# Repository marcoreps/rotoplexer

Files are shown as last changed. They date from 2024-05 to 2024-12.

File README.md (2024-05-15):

# rotoplexer
 Nanovolt scanner with rotary switches, first draft for experimentation only

Inspired by
https://dataproof.com/Publications/NBS430.PDF
https://iopscience.iop.org/article/10.1088/0957-0233/24/2/025008

Python software example
https://github.com/marcoreps/multiinstrumentalist/blob/11b641b6d90bda38c73909955b253200de4179e4/main.py#L624

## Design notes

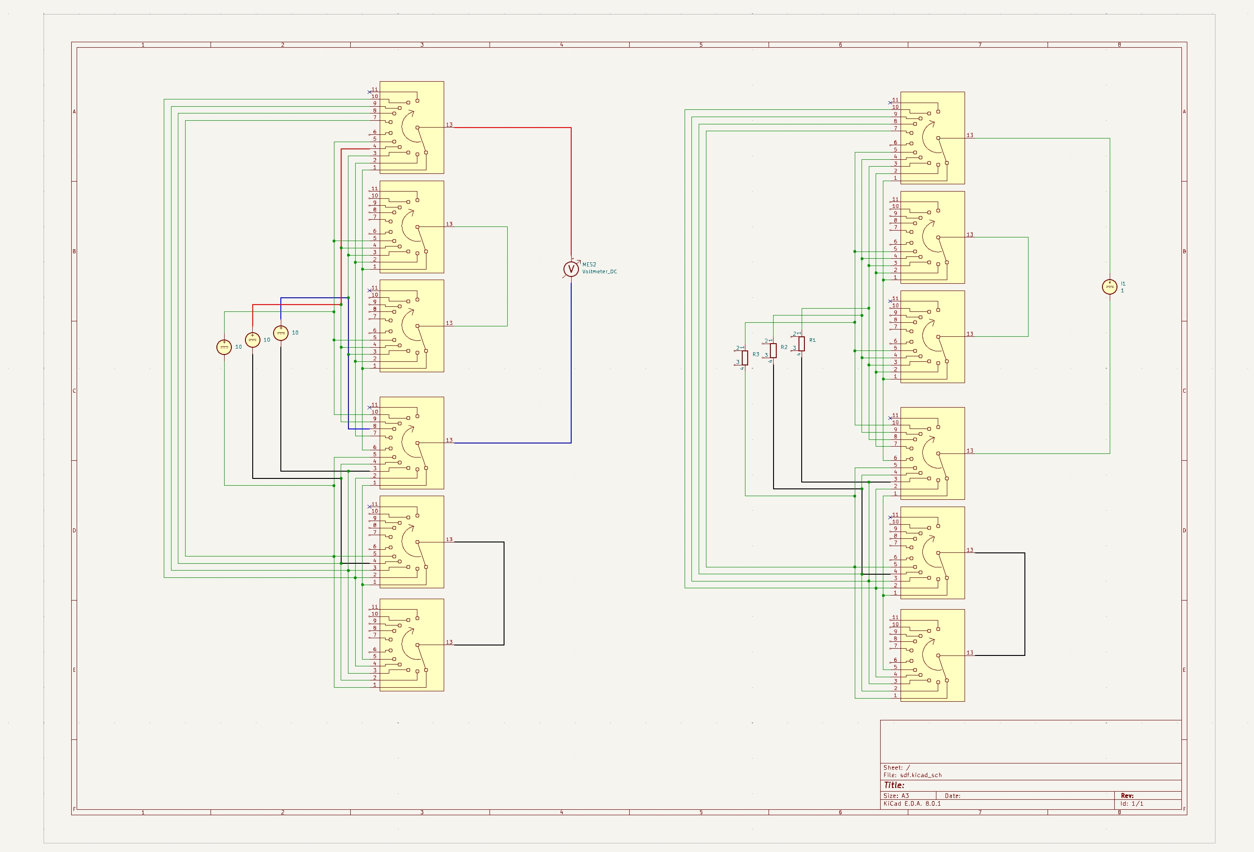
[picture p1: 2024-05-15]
electronics/nbs430 switch example.jpg

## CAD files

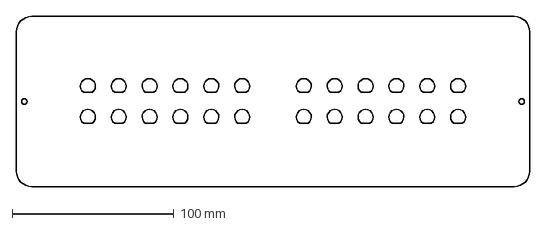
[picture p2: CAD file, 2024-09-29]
3d models/frontpanel.dxf
317.0 x 105.0 mm

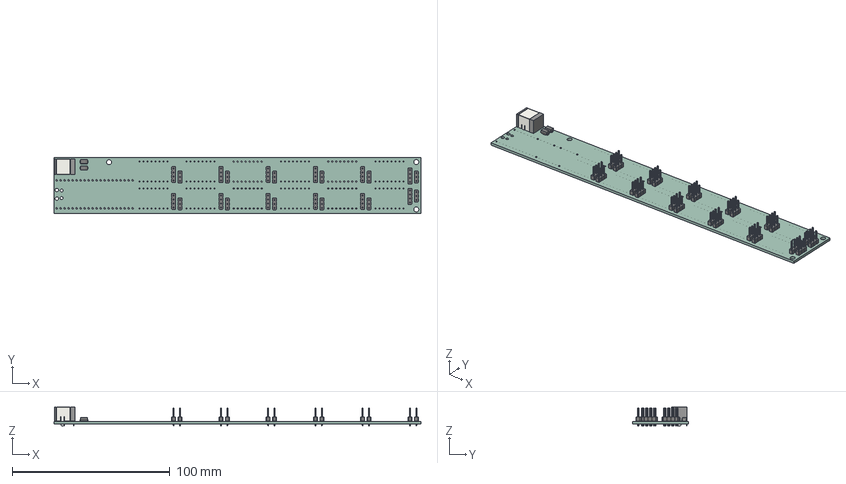
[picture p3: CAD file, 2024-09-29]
electronics/controller board/controller board.step
233.0 x 35.6 x 12.0 mm
PinHeader_1x04_P254mm_Vertical x 12
PinHeader_1x03_P254mm_Vertical x 12
D_SMA x 2
BarrelJack_CUI_PJ-063AH_Horizontal
controller board_PCB

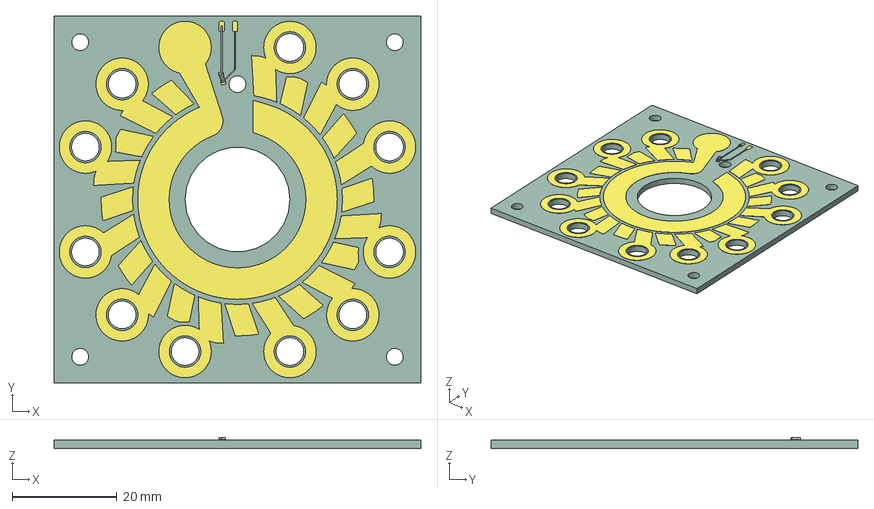
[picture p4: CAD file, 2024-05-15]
electronics/switch wafer pcb/rotary_switch_nv_scanner.step
70.0 x 70.0 x 2.10 mm
R_0603_1608Metric
rotary_switch_nv_scanner_track_1
rotary_switch_nv_scanner_track_2
rotary_switch_nv_scanner_track_3
rotary_switch_nv_scanner_track_4
rotary_switch_nv_scanner_track_5
rotary_switch_nv_scanner_track_6
rotary_switch_nv_scanner_track_7
rotary_switch_nv_scanner_track_8
rotary_switch_nv_scanner_track_9
rotary_switch_nv_scanner_track_10
rotary_switch_nv_scanner_track_11
rotary_switch_nv_scanner_track_12
rotary_switch_nv_scanner_track_13
rotary_switch_nv_scanner_track_14
rotary_switch_nv_scanner_track_15
rotary_switch_nv_scanner_track_16
rotary_switch_nv_scanner_track_17
rotary_switch_nv_scanner_track_18
rotary_switch_nv_scanner_track_19
rotary_switch_nv_scanner_track_20
rotary_switch_nv_scanner_track_21
rotary_switch_nv_scanner_track_22
rotary_switch_nv_scanner_track_23
rotary_switch_nv_scanner_track_24
rotary_switch_nv_scanner_track_25
rotary_switch_nv_scanner_track_26
rotary_switch_nv_scanner_track_27
rotary_switch_nv_scanner_pad_1
rotary_switch_nv_scanner_pad_2
rotary_switch_nv_scanner_pad_3
rotary_switch_nv_scanner_pad_4
rotary_switch_nv_scanner_pad_5
rotary_switch_nv_scanner_pad_6
rotary_switch_nv_scanner_pad_7
rotary_switch_nv_scanner_pad_8
rotary_switch_nv_scanner_pad_9
rotary_switch_nv_scanner_pad_10
rotary_switch_nv_scanner_pad_11
rotary_switch_nv_scanner_pad_12
rotary_switch_nv_scanner_pad_13
rotary_switch_nv_scanner_pad_14
rotary_switch_nv_scanner_PCB

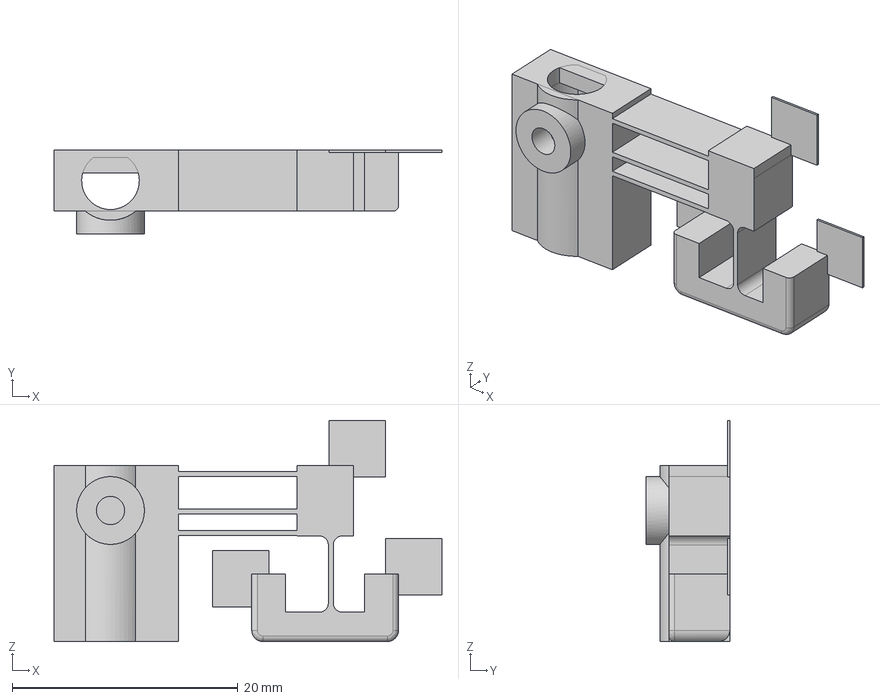
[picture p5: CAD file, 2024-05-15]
3d models/fdm wiper.step
34.3 x 7.40 x 19.6 mm

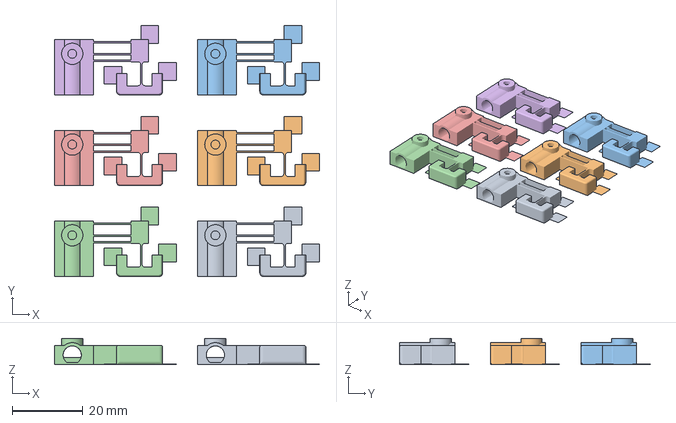
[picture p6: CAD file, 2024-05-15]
3d models/asa 6 wipers prusaslicer.3mf
74.7 x 70.7 x 7.40 mm

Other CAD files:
3d models/fdm wiper.stl

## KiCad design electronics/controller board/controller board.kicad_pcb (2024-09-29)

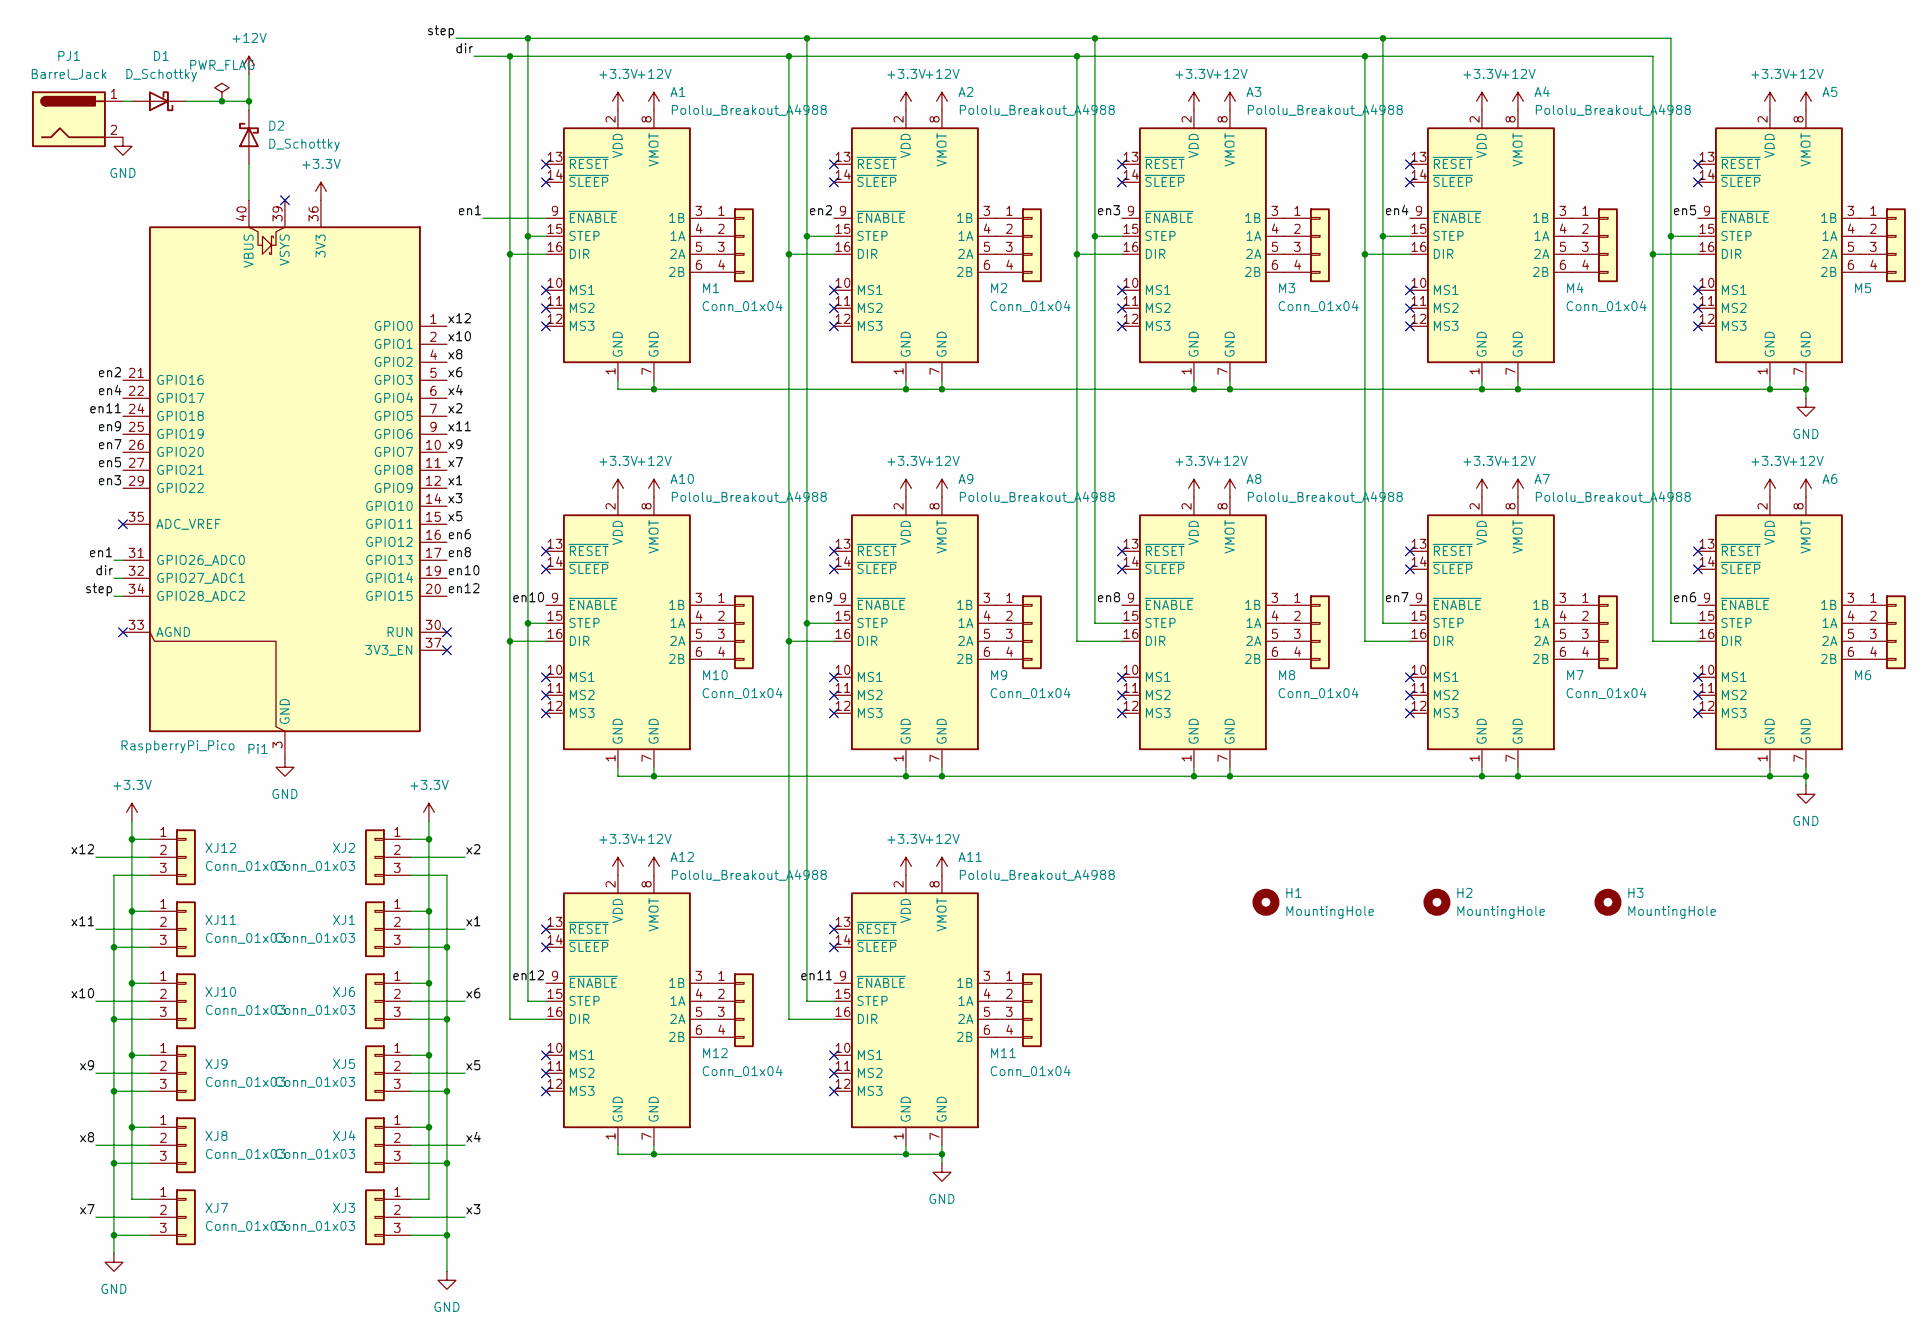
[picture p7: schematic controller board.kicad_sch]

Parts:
A1, A2, A3, A4, A5, A6, A7, A8, A9, A10, A11, A12: Pololu_Breakout_A4988; Pololu_Breakout-16_15.2x20.3mm
D1, D2: D_Schottky; D_SMA
H1, H2, H3: MountingHole; MountingHole_3.2mm_M3
M1, M2, M3, M4, M5, M6, M7, M8, M9, M10, M11, M12: Conn_01x04; PinHeader_1x04_P2.54mm_Vertical
PJ1: Barrel_Jack; BarrelJack_CUI_PJ-063AH_Horizontal
Pi1: RaspberryPi_Pico; RaspberryPi_Pico_Common
XJ1, XJ2, XJ3, XJ4, XJ5, XJ6, XJ7, XJ8, XJ9, XJ10, XJ11, XJ12: Conn_01x03; PinHeader_1x03_P2.54mm_Vertical

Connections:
+3.3V: A1.2 (VDD), A2.2 (VDD), A3.2 (VDD), A4.2 (VDD), A5.2 (VDD), A6.2 (VDD), A7.2 (VDD), A8.2 (VDD), A9.2 (VDD), A10.2 (VDD), A11.2 (VDD), A12.2 (VDD), Pi1.36 (3V3), XJ1.1, XJ2.1, XJ3.1, XJ4.1, XJ5.1, XJ6.1, XJ7.1, XJ8.1, XJ9.1, XJ10.1, XJ11.1, XJ12.1
+12V: A1.8 (VMOT), A2.8 (VMOT), A3.8 (VMOT), A4.8 (VMOT), A5.8 (VMOT), A6.8 (VMOT), A7.8 (VMOT), A8.8 (VMOT), A9.8 (VMOT), A10.8 (VMOT), A11.8 (VMOT), A12.8 (VMOT), D1.1 (K), D2.1 (K)
/dir: A1.16 (DIR), A2.16 (DIR), A3.16 (DIR), A4.16 (DIR), A5.16 (DIR), A6.16 (DIR), A7.16 (DIR), A8.16 (DIR), A9.16 (DIR), A10.16 (DIR), A11.16 (DIR), A12.16 (DIR), Pi1.32 (GPIO27_ADC1)
/en1: A1.9 (~ENABLE), Pi1.31 (GPIO26_ADC0)
/en2: A2.9 (~ENABLE), Pi1.21 (GPIO16)
/en3: A3.9 (~ENABLE), Pi1.29 (GPIO22)
/en4: A4.9 (~ENABLE), Pi1.22 (GPIO17)
/en5: A5.9 (~ENABLE), Pi1.27 (GPIO21)
/en6: A6.9 (~ENABLE), Pi1.16 (GPIO12)
/en7: A7.9 (~ENABLE), Pi1.26 (GPIO20)
/en8: A8.9 (~ENABLE), Pi1.17 (GPIO13)
/en9: A9.9 (~ENABLE), Pi1.25 (GPIO19)
/en10: A10.9 (~ENABLE), Pi1.19 (GPIO14)
/en11: A11.9 (~ENABLE), Pi1.24 (GPIO18)
/en12: A12.9 (~ENABLE), Pi1.20 (GPIO15)
/step: A1.15 (STEP), A2.15 (STEP), A3.15 (STEP), A4.15 (STEP), A5.15 (STEP), A6.15 (STEP), A7.15 (STEP), A8.15 (STEP), A9.15 (STEP), A10.15 (STEP), A11.15 (STEP), A12.15 (STEP), Pi1.34 (GPIO28_ADC2)
/x1: Pi1.12 (GPIO9), XJ1.2
/x2: Pi1.7 (GPIO5), XJ2.2
/x3: Pi1.14 (GPIO10), XJ3.2
/x4: Pi1.6 (GPIO4), XJ4.2
/x5: Pi1.15 (GPIO11), XJ5.2
/x6: Pi1.5 (GPIO3), XJ6.2
/x7: Pi1.11 (GPIO8), XJ7.2
/x8: Pi1.4 (GPIO2), XJ8.2
/x9: Pi1.10 (GPIO7), XJ9.2
/x10: Pi1.2 (GPIO1), XJ10.2
/x11: Pi1.9 (GPIO6), XJ11.2
/x12: Pi1.1 (GPIO0), XJ12.2
GND: A1.1 (GND), A1.7 (GND), A2.1 (GND), A2.7 (GND), A3.1 (GND), A3.7 (GND), A4.1 (GND), A4.7 (GND), A5.1 (GND), A5.7 (GND), A6.1 (GND), A6.7 (GND), A7.1 (GND), A7.7 (GND), A8.1 (GND), A8.7 (GND), A9.1 (GND), A9.7 (GND), A10.1 (GND), A10.7 (GND), A11.1 (GND), A11.7 (GND), A12.1 (GND), A12.7 (GND), PJ1.2, Pi1.3 (GND), Pi1.8 (GND), Pi1.13 (GND), Pi1.18 (GND), Pi1.23 (GND), Pi1.28 (GND), Pi1.38 (GND), XJ1.3, XJ2.3, XJ3.3, XJ4.3, XJ5.3, XJ6.3, XJ7.3, XJ8.3, XJ9.3, XJ10.3, XJ11.3, XJ12.3
unnamed: A1.4 (1A), M1.2
unnamed: A1.3 (1B), M1.1
unnamed: A1.5 (2A), M1.3
unnamed: A1.6 (2B), M1.4
unnamed: A2.4 (1A), M2.2
unnamed: A2.3 (1B), M2.1
unnamed: A2.5 (2A), M2.3
unnamed: A2.6 (2B), M2.4
unnamed: A3.4 (1A), M3.2
unnamed: A3.3 (1B), M3.1
unnamed: A3.5 (2A), M3.3
unnamed: A3.6 (2B), M3.4
unnamed: A4.4 (1A), M4.2
unnamed: A4.3 (1B), M4.1
unnamed: A4.5 (2A), M4.3
unnamed: A4.6 (2B), M4.4
unnamed: A5.4 (1A), M5.2
unnamed: A5.3 (1B), M5.1
unnamed: A5.5 (2A), M5.3
unnamed: A5.6 (2B), M5.4
unnamed: A6.4 (1A), M6.2
unnamed: A6.3 (1B), M6.1
unnamed: A6.5 (2A), M6.3
unnamed: A6.6 (2B), M6.4
unnamed: A7.4 (1A), M7.2
unnamed: A7.3 (1B), M7.1
unnamed: A7.5 (2A), M7.3
unnamed: A7.6 (2B), M7.4
unnamed: A8.4 (1A), M8.2
unnamed: A8.3 (1B), M8.1
unnamed: A8.5 (2A), M8.3
unnamed: A8.6 (2B), M8.4
unnamed: A9.4 (1A), M9.2
unnamed: A9.3 (1B), M9.1
unnamed: A9.5 (2A), M9.3
unnamed: A9.6 (2B), M9.4
unnamed: A10.4 (1A), M10.2
unnamed: A10.3 (1B), M10.1
unnamed: A10.5 (2A), M10.3
unnamed: A10.6 (2B), M10.4
unnamed: A11.4 (1A), M11.2
unnamed: A11.3 (1B), M11.1
unnamed: A11.5 (2A), M11.3
unnamed: A11.6 (2B), M11.4
unnamed: A12.4 (1A), M12.2
unnamed: A12.3 (1B), M12.1
unnamed: A12.5 (2A), M12.3
unnamed: A12.6 (2B), M12.4
unnamed: D1.2 (A), PJ1.1
unnamed: D2.2 (A), Pi1.40 (VBUS)

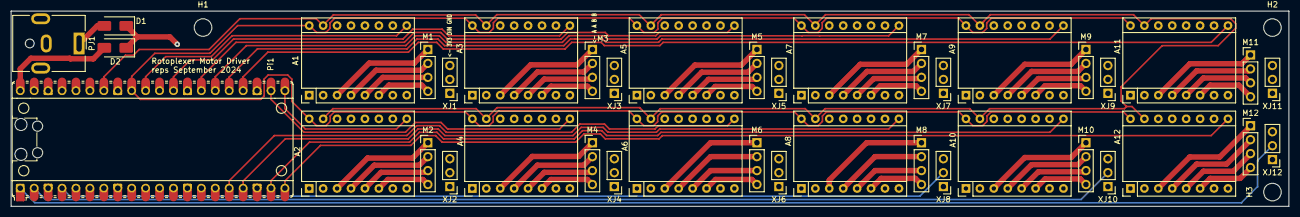
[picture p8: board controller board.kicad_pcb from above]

Board: 4 copper layers, 233.0 x 35.6 mm, 43 parts (0 on the bottom side), 79 nets.

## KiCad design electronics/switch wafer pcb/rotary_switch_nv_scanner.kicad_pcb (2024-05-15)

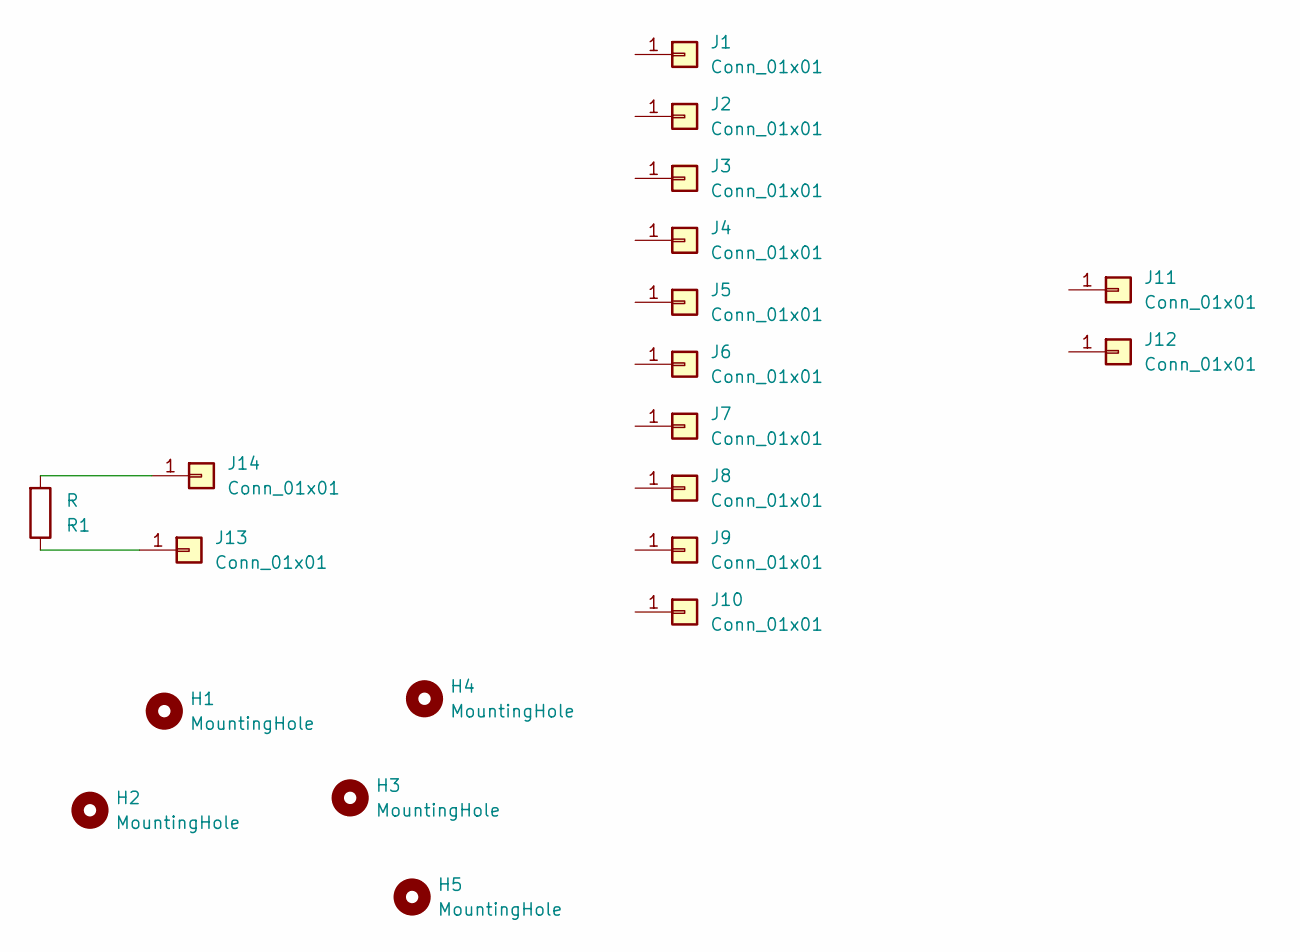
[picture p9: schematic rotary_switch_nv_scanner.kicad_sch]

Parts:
H1, H2, H3, H4, H5: MountingHole; MountingHole_3.2mm_M3
J1, J2, J3, J4, J5, J6, J7, J8, J9, J10, J11, J12: Conn_01x01; MountingHole_metal_pcb
J13, J14: Conn_01x01; SolderWirePad_1x01_SMD_1x2mm
R1: R; R_0603_1608Metric

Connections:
unnamed: J13.1, R1.1
unnamed: J14.1, R1.2

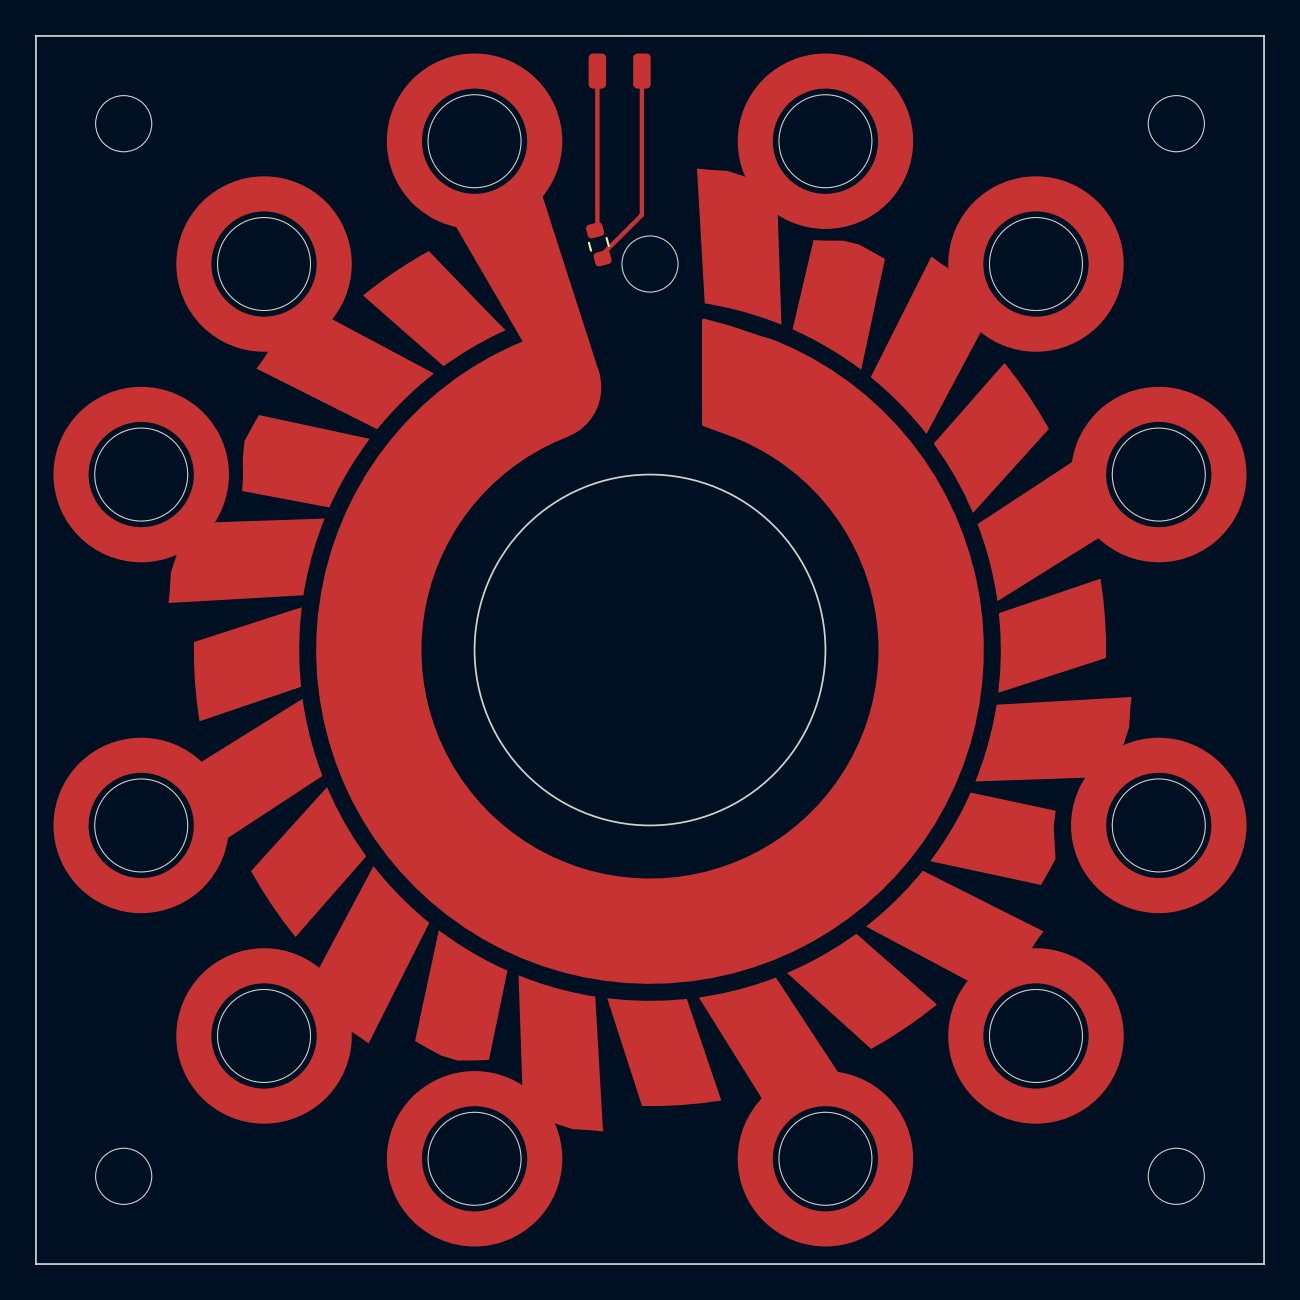
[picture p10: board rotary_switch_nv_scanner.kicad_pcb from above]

Board: 2 copper layers, 70.0 x 70.0 mm, 20 parts (0 on the bottom side), 2 nets.

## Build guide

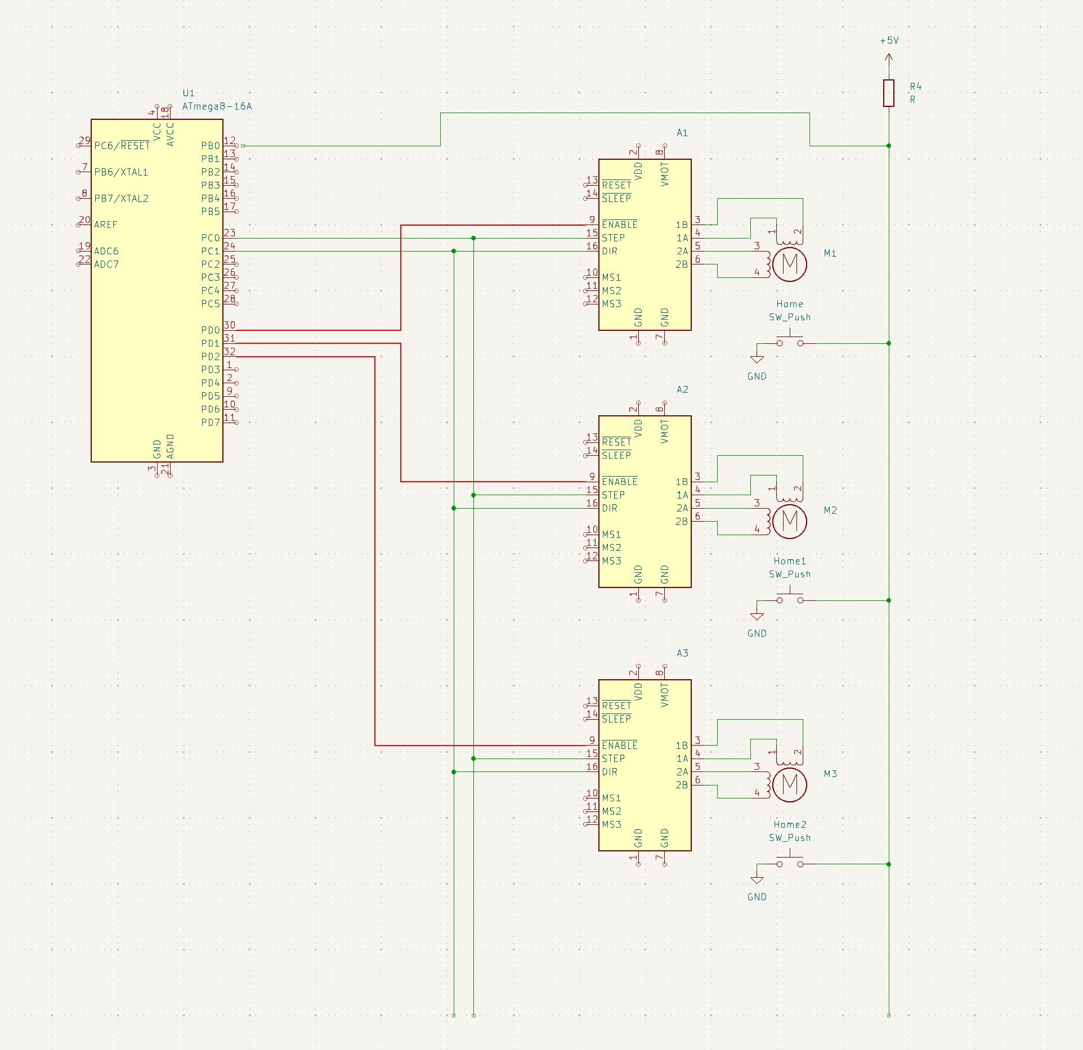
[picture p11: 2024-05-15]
electronics/step direction control example.jpg

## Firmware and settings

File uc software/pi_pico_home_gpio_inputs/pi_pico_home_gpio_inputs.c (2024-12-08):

#include <stdio.h>
#include "pico/stdlib.h"
#include "hardware/gpio.h"

#define STEP_pin 28
#define DIR_pin 27
#define MICROSTEPS 8
#define DELAY_ms 10
#define STEP_LENGTH_ms 1

typedef struct{
   int en_pin;
   int home_pin;
   int zero_offset;
   int position;
} axis;

axis axes[12];

bool homing_commanded = 0;
bool move_commanded = 0;
int active_axis = 0;
int destination = 0;

int calculate_steps_from_switch_pos(int switch_pos){
  return (200*MICROSTEPS/12)*switch_pos;
}

int round_to_fullsteps(int numToRound){
  // We disable drivers when not in use, causing motors to snap to the nearest full step.
  // Doing this often accumulates a position error, so we should only halt at full steps.
  int remainder = numToRound % (MICROSTEPS*4);
  if (remainder == 0)
    return numToRound;
  if (remainder >= MICROSTEPS*2)
    return numToRound + MICROSTEPS*4 - remainder;
  else
    return numToRound - remainder;
}

void update_dir(){
  gpio_put(DIR_pin, (destination < axes[active_axis].position));
  sleep_ms(DELAY_ms);
}

void process_command(char *command){
  printf(command);
  printf(":");
  if (command[0] > 96 && command[0] < 109){
    if (command[0]-97 != active_axis){
      active_axis = command[0]-97;
      printf("change driver to ");
      printf("%d",command[0]-97);
      printf(":");
    }
    if (command[1]=='0'){
      // If commanded destination is 0 we go home
      destination=-1;
      update_dir();
      gpio_put(axes[active_axis].en_pin, 0);
      sleep_ms(DELAY_ms);

      printf("homing commanded:");
      homing_commanded = 1;
      return;
    }
    if(command[1] > 48 && command[1] < 60){
      // Otherwise we go to destination
      // Switch positions 123456789:;
      destination=calculate_steps_from_switch_pos(command[1]%12);
      destination-=axes[active_axis].zero_offset;
      destination=round_to_fullsteps(destination);

      if (destination == axes[active_axis].position){
        printf("done\n");
        return;
      }

      update_dir();
      gpio_put(axes[active_axis].en_pin, 0);
      sleep_ms(DELAY_ms);
      move_commanded = 1;
      printf("dest ");
      printf("%d",destination);
      printf(":");
      printf("pos ");
      printf("%d",axes[active_axis].position);
      printf(":");
    }
    else
      printf("position out of range 0 ... ;\n");
  return;
  }
  else
    printf("axis out of range a ... l\n");
  return;
}

void serial_available(void* cmd){
  // receive characters from serial
  volatile signed char *c = (signed char *) cmd;
  while ((*c = getchar_timeout_us(0)) > 0)
      c++;
  *c = '\0';
}

void wiggle(){
  int last=0;
  for(int i=6;i>=0;i--){
    gpio_put(DIR_pin, (i%2 == 0));
    sleep_ms(DELAY_ms);
    int j=(i+last)*MICROSTEPS;
    last = i;
    while(j){
      gpio_put(STEP_pin, 1);
      sleep_ms(STEP_LENGTH_ms);
      gpio_put(STEP_pin, 0);
      sleep_ms(STEP_LENGTH_ms);
      j--;
      if (!gpio_get(DIR_pin))
        axes[active_axis].position++;
      else
        axes[active_axis].position--;
    }
  }
}

void move_worker(){
  gpio_put(STEP_pin, 1);
  sleep_ms(STEP_LENGTH_ms);
  gpio_put(STEP_pin, 0);
  sleep_ms(STEP_LENGTH_ms);
  if (!gpio_get(DIR_pin))
    axes[active_axis].position++;
  else
    axes[active_axis].position--;

  if (destination == axes[active_axis].position){
    move_commanded=0;
    sleep_ms(DELAY_ms);
    wiggle();
    gpio_put(axes[active_axis].en_pin, 1);
    sleep_ms(DELAY_ms);
    printf("done\n");
  }
}

void home_worker(){
  if (gpio_get(axes[active_axis].home_pin)){
    // Snap to nearest full step
    gpio_put(axes[active_axis].en_pin, 1);
    sleep_ms(DELAY_ms);
    gpio_put(axes[active_axis].en_pin, 0);
    sleep_ms(DELAY_ms);
    axes[active_axis].position=0;
    destination=calculate_steps_from_switch_pos(1);
    destination-=axes[active_axis].zero_offset;
    destination=round_to_fullsteps(destination);
    update_dir();
    move_commanded = 1;
    homing_commanded = 0;
  }
  else{
    gpio_put(STEP_pin, 1);
    sleep_ms(STEP_LENGTH_ms*2);
    gpio_put(STEP_pin, 0);
    sleep_ms(STEP_LENGTH_ms*2);
  }
}

int main(){

  axes[0].en_pin=26;
  axes[0].home_pin=9;
  axes[0].zero_offset=455; //a
  axes[0].position=0;

  axes[1].en_pin=16;
  axes[1].home_pin=5;
  axes[1].zero_offset=0; //b
  axes[1].position=0;

  axes[2].en_pin=22;
  axes[2].home_pin=10;
  axes[2].zero_offset=520; //c
  axes[2].position=0;

  axes[3].en_pin=17;
  axes[3].home_pin=4;
  axes[3].zero_offset=0; //d
  axes[3].position=0;

  axes[4].en_pin=21;
  axes[4].home_pin=11;
  axes[4].zero_offset=230; //e
  axes[4].position=0;

  axes[5].en_pin=12;
  axes[5].home_pin=3;
  axes[5].zero_offset=0; //f
  axes[5].position=0;

  axes[6].en_pin=20;
  axes[6].home_pin=8;
  axes[6].zero_offset=65; //g
  axes[6].position=0;

  axes[7].en_pin=13;
  axes[7].home_pin=2;
  axes[7].zero_offset=0; //h
  axes[7].position=0;

  axes[8].en_pin=19;
  axes[8].home_pin=7;
  axes[8].zero_offset=335; //i
  axes[8].position=0;

  axes[9].en_pin=14;
  axes[9].home_pin=1;
  axes[9].zero_offset=0; //j
  axes[9].position=0;

  axes[10].en_pin=18;
  axes[10].home_pin=6;
  axes[10].zero_offset=1005; //k
  axes[10].position=0;

  axes[11].en_pin=15;
  axes[11].home_pin=0;
  axes[11].zero_offset=0; //l
  axes[11].position=0;

  for (int i; i<12; i++){
    gpio_init(axes[i].en_pin);
    gpio_set_dir(axes[i].en_pin, GPIO_OUT);
    gpio_put(axes[i].en_pin, 1);
    gpio_init(axes[i].home_pin);
    gpio_set_dir(axes[i].home_pin, GPIO_IN);
  }

  gpio_init(STEP_pin);
  gpio_set_dir(STEP_pin, GPIO_OUT);
  gpio_init(DIR_pin);
  gpio_set_dir(DIR_pin, GPIO_OUT);

  stdio_init_all();
  sleep_ms(1000);

  printf("Here goes nothin ...\n");

  // TODO Crash if longer strings are received?
  // TODO Terrible things happen if we interrupt an operation with another cmd
  static signed char serialString[32] = {0};
  stdio_set_chars_available_callback(&serial_available, (void*) serialString);

  while (1) {
    if (serialString[0]){
      process_command(serialString);
      serialString[0] = '\0';
    }
    if (move_commanded)
      move_worker();
    if(homing_commanded)
      home_worker();
  }
}

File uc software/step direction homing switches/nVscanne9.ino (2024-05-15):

#include <AccelStepper.h>

#define STEP 22
#define DIR 24
#define HOME 26
#define MAXSPEED 500
#define ACCELERATION 5000
#define MICROSTEPS 8

AccelStepper stepper(AccelStepper::DRIVER, STEP, DIR);

typedef struct{
   int en_pin;
   long position=0;
} axis;

axis axes[12];

boolean homing_commanded = 0;
boolean move_commanded = 0;
int active_axis = 0;
long destination = 0;


long calculate_steps_from_switch_pos(int switch_pos){
    return (200*MICROSTEPS/12)*switch_pos;
}


void process_command(String command){
  Serial.print(command);
  Serial.print(":");
  if(command.length()>4||command.length()<2)
    return;
  if (isAlpha(command[0])&&command[0]<'m'){
    if (tolower(command[0])-97 != active_axis){
      active_axis = tolower(command[0])-97;
      stepper.setCurrentPosition(axes[active_axis].position);
      Serial.print("changedriverto ");
      Serial.print(tolower(command[0])-97);
      Serial.print(":");
    }
    if (!(destination=command.substring(1).toInt()%12)){
      homing_commanded = 1;
      stepper.setSpeed(MAXSPEED*-0.5);
      return;
    }
    else
      move_commanded = 1;
      Serial.print("dest ");
      Serial.print(calculate_steps_from_switch_pos(destination));
      Serial.print(":");
      stepper.moveTo(calculate_steps_from_switch_pos(destination));
  }
  return;
}




void setup()
{
  axes[0].en_pin=28;
  axes[1].en_pin=30;
  axes[2].en_pin=32;
  axes[3].en_pin=34;
  axes[4].en_pin=42;
  axes[5].en_pin=40;

  axes[6].en_pin=40;
  axes[7].en_pin=42;
  axes[8].en_pin=44;
  axes[9].en_pin=46;
  axes[10].en_pin=48;
  axes[11].en_pin=50;

  pinMode(axes[0].en_pin, OUTPUT);
  digitalWrite(axes[0].en_pin, HIGH);
  pinMode(axes[1].en_pin, OUTPUT);
  digitalWrite(axes[1].en_pin, HIGH);
  pinMode(axes[2].en_pin, OUTPUT);
  digitalWrite(axes[2].en_pin, HIGH);
  pinMode(axes[3].en_pin, OUTPUT);
  digitalWrite(axes[3].en_pin, HIGH);
  pinMode(axes[4].en_pin, OUTPUT);
  digitalWrite(axes[4].en_pin, HIGH);
  pinMode(axes[5].en_pin, OUTPUT);
  digitalWrite(axes[5].en_pin, HIGH);

  pinMode(HOME, INPUT_PULLUP);

  stepper.setMaxSpeed(MAXSPEED);
  stepper.setAcceleration(ACCELERATION);

  Serial.begin(115200);
  while(!Serial);
}



void loop()
{

  if(homing_commanded){
    if (!digitalRead(HOME)){
      stepper.stop();
      stepper.setCurrentPosition(0);
      stepper.runToNewPosition(30);
      digitalWrite(axes[active_axis].en_pin, HIGH);
      axes[active_axis].position=0;
      stepper.setCurrentPosition(0);
      homing_commanded = 0;
      Serial.println("homed");
      return;
    }
    else{
      digitalWrite(axes[active_axis].en_pin, LOW);
      //Serial.println("homing");
      stepper.runSpeed();
      return;
    }
  }


  if(move_commanded){
    if (!stepper.distanceToGo()){
      digitalWrite(axes[active_axis].en_pin, HIGH);
      move_commanded = 0;
      axes[active_axis].position = stepper.currentPosition();
      Serial.print("reported pos ");
      Serial.print(stepper.currentPosition());
      Serial.print(":");
      Serial.println("done");
      return;
    }
    else{
      digitalWrite(axes[active_axis].en_pin, LOW);
      stepper.run();
      return;
    }
  }


  if (Serial.available())
    process_command(Serial.readStringUntil('\n'));

}
